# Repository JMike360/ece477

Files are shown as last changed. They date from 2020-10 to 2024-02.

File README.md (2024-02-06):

# ece477
Purdue ECE senior design project of team 8 for Fall 2020  
  
## Team members
John Michael Bolinder (Team leader, software engineer, systems engineer)  
Ethan Rodriguez (Systems engineer, secondary software engineer)  
Jiahui Zhu (Software engineer, secondary hardware engineer)  
Andrew Gan (Hardware engineer, secondary systems engineer)  

## Overview
Skeleton Key is a convenient, fully-featured password management solution, completely client-side with no dependence on a cloud service provider or network connection. The device utilizes an ESP32 microcontroller and onboard peripherals to manage encrypted-at-rest password storage, fingerprint-based authentication for easy and secure access to passwords, and interfaces with a client desktop app to wirelessly retrieve passwords via bluetooth or retrieve passwords through a wired USB connection. Passwords transmitted by USB or Bluetooth are encrypted in-flight, and the desktop application provides easy access to passwords on the target user device.
  
## Tools used
USB URT module  
ESP32  
Fingerprint reader  
SD card  
SD card reader  
LCD module  
  
## GPIO table
| GPIO PIN | Function  | Endpoint |
|---|---|---|
| 1 | U0TXD | FT232 RXD |
| 3 | U0RXD | FT232 TXD |
| 9 | U1RXD | Console in |
| 10 | U1TXD | Console_out  |
| 12 | HSPI_MISO | MicroSD Dout |
| 13 | HSPI_MOSI | MicroSD Din  |
| 14 | HSPI_CLK  | MicroSD CLK  |
| 15 | HSPI_CS0  | MicroSD CS |
| 16 | U2RXD | Fingerprint Scanner TX |
| 17 | U2TXD | Fingerprint Scanner RX |
  
UART 0: console/debug  
UART 1: ESP32 - GUI  
UART 2: ESP32 - Fingerprint  
  
GPIO 6-11 - SPI flash  
GPIO 34-39 - input mode only    
[Full layout](https://microcontrollerslab.com/wp-content/uploads/2019/02/ESP32-pinout-mapping.png)  
ESP32 tech ref manual page 57-58  
  
## References
[ESP32 SPI MASTER API](https://docs.espressif.com/projects/esp-idf/en/latest/esp32/api-reference/peripherals/spi_master.html)

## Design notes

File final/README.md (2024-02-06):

# ESP32 Embedded Software for management of at-rest AES encryption/decryption and in-flight RSA encryption/decryption

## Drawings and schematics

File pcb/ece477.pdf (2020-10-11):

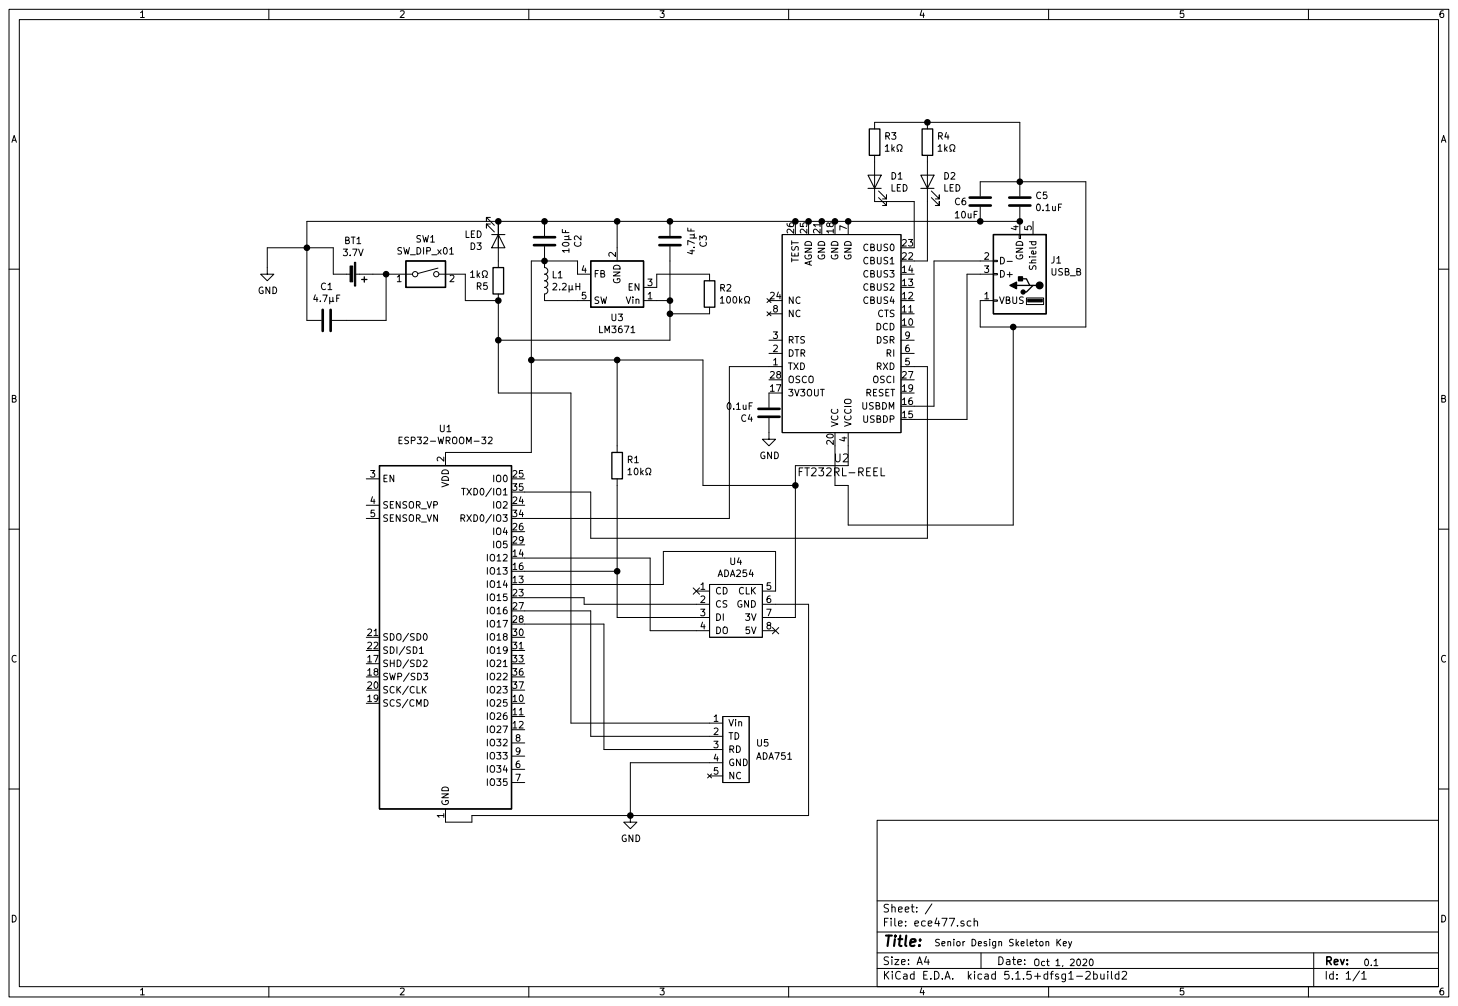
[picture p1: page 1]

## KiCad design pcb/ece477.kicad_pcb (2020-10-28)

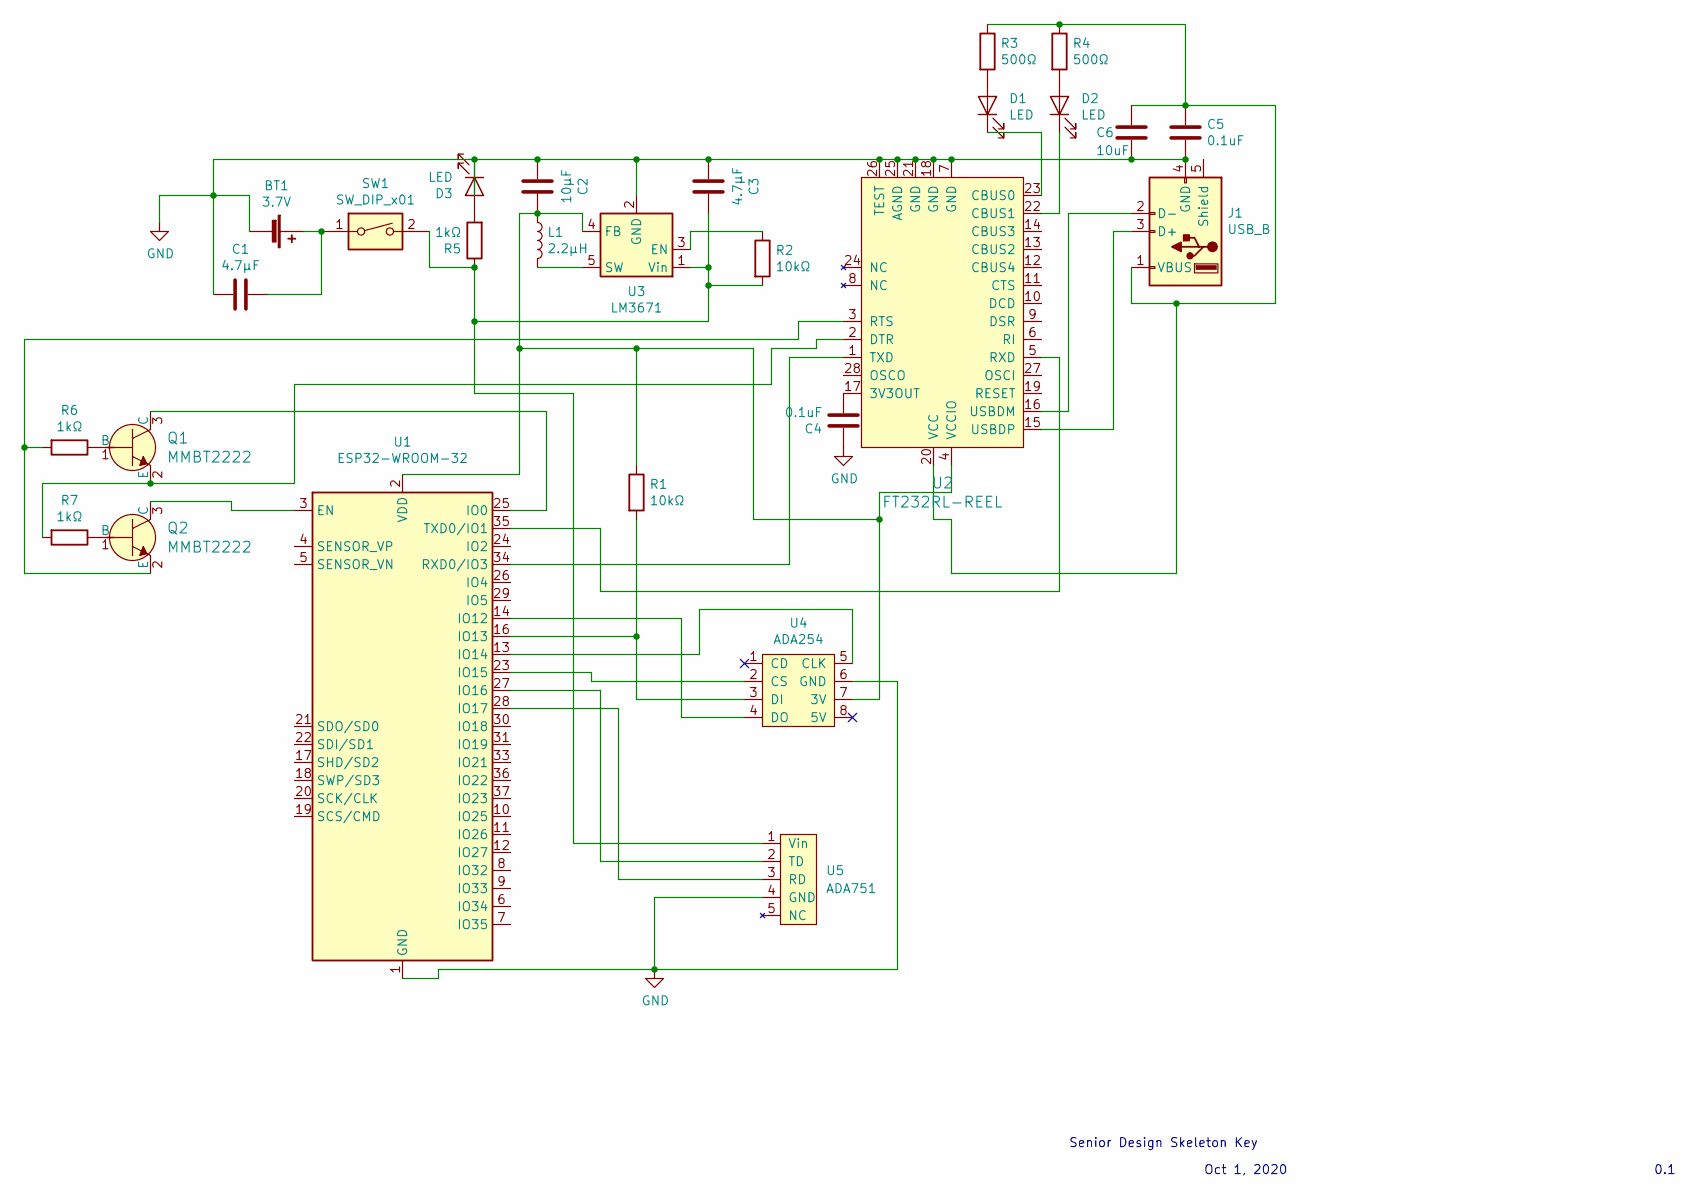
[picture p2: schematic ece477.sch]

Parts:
BT1: 3.7V; PinHeader_1x02_P2.54mm_Vertical
C1, C3: 4.7µF; C_0805_2012Metric
C2: 10µF; C_0805_2012Metric
C4, C5: 0.1uF; C_0805_2012Metric
C6: 10uF; C_0805_2012Metric
D1, D2, D3: LED; LED_0805_2012Metric
J1: USB_B; USB_Micro-B_Molex_47346-0001
L1: 2.2µH; IND_LQH3NPN2R2MMEL
Q1, Q2: MMBT2222; SOT-23-3; MPN MMBT2222A-7-F; Digi-Key_PN MMBT2222A-FDICT-ND
R1, R2: 10kΩ; R_0805_2012Metric
R3, R4: 500Ω; R_0805_2012Metric
R5, R6, R7: 1kΩ; R_0805_2012Metric
SW1: SW_DIP_x01; SW_DIP_SPSTx01_Slide_6.7x4.1mm_W6.73mm_P2.54mm_LowProfile_J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
U1: ESP32-WROOM-32; ESP32-WROOM-32D
U2: FT232RL-REEL; SSOP-28_W5.30mm; MPN FT232RL-REEL; Digi-Key_PN 768-1007-1-ND
U3: LM3671; TSOT-23-5
U4: ADA254; PinSocket_1x08_P2.54mm_Vertical
U5: ADA751; PinHeader_1x05_P2.54mm_Vertical

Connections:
GND: BT1.2 (-), C1.1, C2.1, C3.1, C4.1, C5.2, C6.2, D3.1 (K), J1.4 (GND), U1.1 (GND), U1.15 (GND), U1.38 (GND), U1.39 (GND), U2.7 (GND), U2.18 (GND), U2.21 (GND), U2.25 (AGND), U2.26 (TEST), U3.2 (GND), U4.6 (GND), U5.4 (GND)
unnamed: BT1.1 (+), C1.2, SW1.1
unnamed: C2.2, L1.1, R1.1, U1.2 (VDD), U2.4 (VCCIO), U3.4 (FB), U4.7 (3V)
unnamed: C3.2, R2.2, R5.1, SW1.2, U3.1 (Vin), U5.1 (Vin)
unnamed: C4.2, U2.17 (3V3OUT)
unnamed: C5.1, C6.1, J1.1 (VBUS), R3.1, R4.1, U2.20 (VCC)
unnamed: D1.1 (K), U2.23 (CBUS0)
unnamed: D1.2 (A), R3.2
unnamed: D2.1 (K), U2.22 (CBUS1)
unnamed: D2.2 (A), R4.2
unnamed: D3.2 (A), R5.2
unnamed: J1.2 (D-), U2.16 (USBDM)
unnamed: J1.3 (D+), U2.15 (USBDP)
unnamed: L1.2, U3.5 (SW)
unnamed: Q1.1 (B), R6.1
unnamed: Q1.2 (E), R7.2, U2.2 (DTR)
unnamed: Q1.3 (C), U1.25 (IO0)
unnamed: Q2.1 (B), R7.1
unnamed: Q2.2 (E), R6.2, U2.3 (RTS)
unnamed: Q2.3 (C), U1.3 (EN)
unnamed: R1.2, U1.16 (IO13), U4.3 (DI)
unnamed: R2.1, U3.3 (EN)
unnamed: U1.13 (IO14), U4.5 (CLK)
unnamed: U1.14 (IO12), U4.4 (DO)
unnamed: U1.23 (IO15), U4.2 (CS)
unnamed: U1.27 (IO16), U5.2 (TD)
unnamed: U1.28 (IO17), U5.3 (RD)
unnamed: U1.34 (RXD0/IO3), U2.1 (TXD)
unnamed: U1.35 (TXD0/IO1), U2.5 (RXD)

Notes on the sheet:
Senior Design Skeleton Key
Oct 1, 2020
0.1

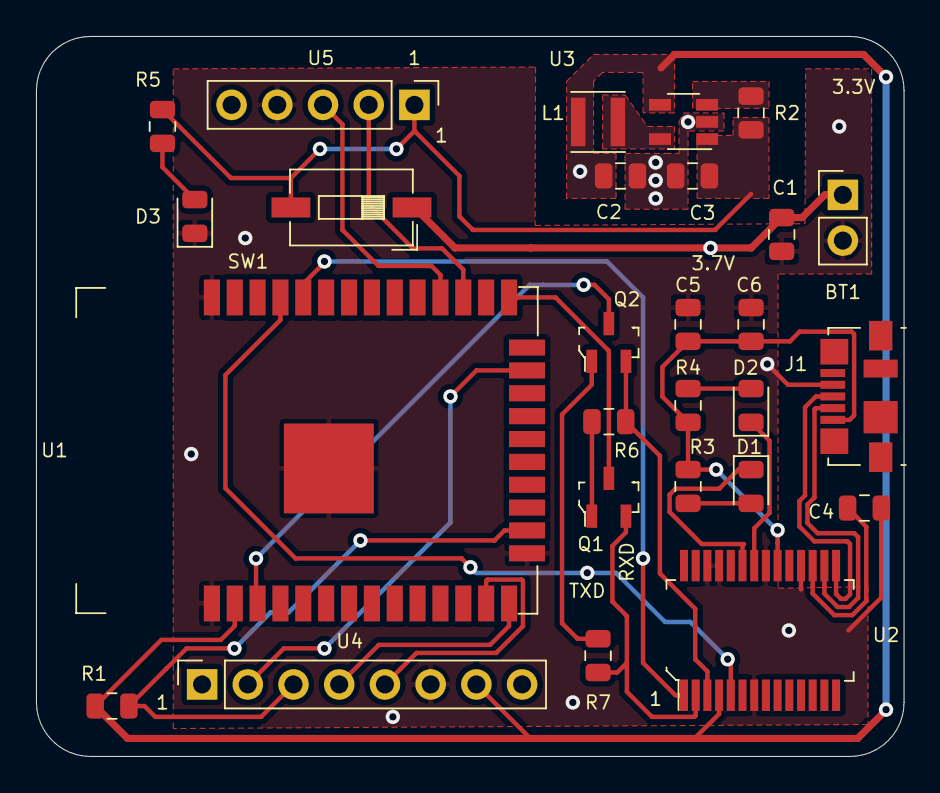
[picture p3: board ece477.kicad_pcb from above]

Board: 2 copper layers, 48.2 x 40.0 mm, 27 parts (0 on the bottom side), 29 nets.

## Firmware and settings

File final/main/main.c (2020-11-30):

#include <stdio.h>
#include <stdbool.h>
#include <string.h>
#include "../include/cmd.h"
#include "freertos/FreeRTOS.h"
#include "freertos/task.h"
#include "sdkconfig.h"
#include "esp_vfs_fat.h"
#include "esp_log.h"
#include <unistd.h>

#include "../include/bt.h"
#include "../include/sdcard.h"
#include "../include/manifest.h"
#include "../include/fingerprint.h"
#include "../include/my_rsa.h"

#define BUF_SIZE_MAIN (1024)
#define TAG "MAIN"

void ledInit(void) {
    gpio_pad_select_gpio(GPIO_GREEN);
    gpio_pad_select_gpio(GPIO_RED);
    gpio_set_direction(GPIO_GREEN, GPIO_MODE_OUTPUT);
    gpio_set_direction(GPIO_RED, GPIO_MODE_OUTPUT);
    ESP_LOGI(TAG, "Successfully initialized LED GPIO");
}

void readUARTCMD(uint8_t* data) {
    int i = 0;
    do {
        i += uart_read_bytes(UART_NUM_0, &data[i], BUF_SIZE_MAIN, 20 / portTICK_RATE_MS);
    } while(data[i-1] != '\n');
    // ESP_LOGI(TAG, "reading from UART: %s\n", data);
    if (data[0] != '#')
        return;
    doCMD(data, UART_MODE);
}

void app_main(void) {
    sdspiInit();
    mountSD();
    ledInit();
    btInit();
    btRegister();
    btSetPairing();
    sleep(2);
    
    uart_begin(UART_NUM_0);
    uart_begin(UART_NUM_2);
    my_rsa_init();

    sleep(2);
    ESP_LOGI(TAG, "All initialization complete");

    while (checkFingerEnrolled() == 0) {
        if (enrollFinger(0) == -1)
            ESP_LOGE(TAG, "Fingerprint enrollment failed");
    }

    if (readManifestToMemory() == MANIFEST_FAILURE)
        return;

    uint8_t* data = (uint8_t*) malloc(BUF_SIZE_MAIN);
    while(getRunning()) {
        memset(data, 0, BUF_SIZE_MAIN);
        readUARTCMD(data);
    }
    free(data);

    if (writeManifestToFile() == MANIFEST_FAILURE)
        return;
    if (deallocateManifest() == MANIFEST_FAILURE)
        return;

    unmountSD();
    uart_end(UART_NUM_0);
    uart_end(UART_NUM_2);
}

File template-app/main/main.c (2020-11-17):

/* Hello World Example

   This example code is in the Public Domain (or CC0 licensed, at your option.)

   Unless required by applicable law or agreed to in writing, this
   software is distributed on an "AS IS" BASIS, WITHOUT WARRANTIES OR
   CONDITIONS OF ANY KIND, either express or implied.
*/
#include <stdio.h>
#include <stdlib.h>
#include "freertos/FreeRTOS.h"
#include "freertos/task.h"
#include "esp_system.h"
#include "esp_spi_flash.h"
#include "crypto_test.h"
#include "fingerprint_test.h"
#include "uart_setup.h"


void app_main(void)
{
    printf("Hello world!\n");

    /* Print chip information */
    esp_chip_info_t chip_info;
    esp_chip_info(&chip_info);
    printf("This is ESP32 chip with %d CPU cores, WiFi%s%s, ",
            chip_info.cores,
            (chip_info.features & CHIP_FEATURE_BT) ? "/BT" : "",
            (chip_info.features & CHIP_FEATURE_BLE) ? "/BLE" : "");

    printf("silicon revision %d, ", chip_info.revision);

    printf("%dMB %s flash\n", spi_flash_get_chip_size() / (1024 * 1024),
            (chip_info.features & CHIP_FEATURE_EMB_FLASH) ? "embedded" : "external");

    for (int i = 10; i >= 0; i--) {
        printf("Restarting in %d seconds...\n", i);
        vTaskDelay(1000 / portTICK_PERIOD_MS);
    }

    encodetest();

    printf("Running test shell\n");
    int cmd = -1;
    const char* const cmdList[] = {
        "0. Exit\n",
        "1. Send Handshake\n",
        "2. Library Handshake\n",
        "3. Library Generate Img\n",
        "4. Library Capture Image\n",
        "5. Library Generate File From Image (Buffer 1)\n",
        "6. Library Generate File From Image (Buffer 2)\n",
        "7. Library Generate Template\n",
        "8. Library Store Template\n",
        "9. Library Match Search\n",
        "10. Library Load Template\n",
        "11. Library Clear All Templates\n",
        "12. Download Fingerprint Image\n",
        "13. Read System Parameters\n",
        "14. Create Crypto Key\n",
        "15. Led Control\n",
        "16. High Level Check Finger Enrolled\n",
        "17. High Level Enroll Finger\n",
        "18. High Level Authenticate Finger\n",
        "19. High Level Get Crypto Key\n",
        "20. High Level Clear All Data\n"
    };
    setupFtdiConsole();
    while (cmd != 0){
        printf("\n\nAvailable commands:\n");
        for(int i = 0; i < 21; i++){
            printf("%s", cmdList[i]);
        }
        printf("Please enter desired sensor command as number...\n");
        cmd = getFtdiCommand();
        printf("\n\n"); 
        switch(cmd){
            case 0:
                printf("Exiting test shell...\n");
                break;
            case 1:
                printf("Running raw handshake command...\n");
                sendHandshake();
                break;
            case 2:
                printf("Running library handshake test...\n");
                testLibraryHandshake();
                break;
            case 3:
                printf("Running library generate image test...\n");
                testLibraryGenImg();
                break;
            case 4:
                printf("Running library capture image test...\n");
                testLibraryCaptureImage();
                break;
            case 5:
                printf("Running library generate file from image (buffer 1) test...\n");
                testLibraryGenerateFileFromImg(0x01);
                break;
            case 6:
                printf("Running library generate file from image (buffer 2) test...\n");
                testLibraryGenerateFileFromImg(0x02);
                break;
            case 7:
                printf("Running library generate template test...\n");
                testLibraryGenerateTemplate();
                break;
            case 8:
                printf("Running library store template test...\n");
                printf("Please enter an ID for storing template...\n");
                uint16_t pageID_store = (uint16_t)getFtdiCommand();
                printf("Storing template under ID: %d...", pageID_store);
                testLibraryStoreTemplate(pageID_store);
                break;
            case 9:
                printf("Running match search test...\n");
                testLibraryMatchSearch(0x01);
                break;
            case 10:
                printf("Running load template test...\n");
                printf("Please enter the template ID to load...\n");
                uint16_t pageID_load = (uint16_t)getFtdiCommand();
                printf("Please enter desired buffer to load to...\n");
                uint8_t bufferID = (uint8_t)getFtdiCommand();
                printf("Attempting to load template %d to buffer %d...\n", pageID_load, bufferID);
                testLibraryLoadTemplate(bufferID, pageID_load);
                break;
            case 11:
                printf("Running clear template library test...\n");
                testLibraryClearTemplates();
                break;
            case 12:
                printf("Running download template file test...\n");
                testLibraryUploadFile(0x01);
                break;
            case 13:
                printf("Running system parameter read test...\n");
                testLibraryReadParam();
                break;
            case 14:
                printf("Running crypto key generation test...\n");
                testLibraryGenerateCryptoKey();
                break;
            case 15:
                printf("Running led control test...\n");
                printf("Please select 1 for led on or 0 for led off...\n");
                int state = getFtdiCommand();
                testLibraryLedCtrl(state);
                break;
            case 16:
                printf("Running high level check finger enrolled...\n");
                testHLcheckFingerEnrolled();
                break;
            case 17:
                printf("Running high level enroll finger...\n");
                testHLenrollFinger();
                break;
            case 18:
                printf("Running high level authenticate finger...\n");
                testHLauthenticateFinger();
                break;
            case 19:
                printf("Running high level get crypto key...\n");
                testHLgetCryptoKey();
                break;
            case 20:
                printf("Running high level clear all data...\n");
                testHLclearAllData();
                break;
            default:
                printf("Unknown command, please select a command from the list\n");
                break;
        }
    }
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

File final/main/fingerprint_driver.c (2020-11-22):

#include "esp_log.h"
#include "../include/fingerprint_driver.h"

#define TAG "FINGERPRINT"

sensor_packet* createPacket(uint8_t pid, uint16_t length, uint8_t* data, uint16_t checksum){
    sensor_packet* pkt = malloc(sizeof(sensor_packet));
    pkt->header = PKT_HEADER;
    pkt->addr[0] = 0xFF;
    pkt->addr[1] = 0xFF;
    pkt->addr[2] = 0xFF;
    pkt->addr[3] = 0xFF;
    pkt->pid = pid;
    pkt->length = length;
    pkt->data = malloc(sizeof(uint8_t)*(length-2));
    for(int i = 0; i < length-2; i++){
        pkt->data[i] = data[i];
    }
    pkt->checksum = checksum;
    return pkt;
}

void freePacket(sensor_packet* pkt){
    free(pkt->data);
    free(pkt);
}

bool isEqual(sensor_packet* pkt1, sensor_packet* pkt2){
    bool isEqual = true;
    isEqual &= (pkt1->header == pkt2->header);
    isEqual &= (pkt1->addr[0] == pkt2->addr[0]);
    isEqual &= (pkt1->addr[1] == pkt2->addr[1]);
    isEqual &= (pkt1->addr[2] == pkt2->addr[2]);
    isEqual &= (pkt1->addr[3] == pkt2->addr[3]);
    isEqual &= (pkt1->pid == pkt2->pid);
    isEqual &= (pkt1->length == pkt2->length);
    for(int i = 0; i < pkt1->length-2; i++){
        if((i >= pkt2->length-2) || (!isEqual)){
            break;
        }
        isEqual &= (pkt1->data[i] == pkt2->data[i]);
    }
    isEqual &= (pkt1->checksum == pkt2->checksum);
    return isEqual;
}

void printPacket(sensor_packet* pkt){
    #ifdef _DEBUG
    ESP_LOGI(TAG, "Header: 0x%04x", pkt->header);
    ESP_LOGI(TAG, "Addr: 0x%02x 0x%02x 0x%02x 0x%02x", pkt->addr[0], pkt->addr[1], pkt->addr[2], pkt->addr[3]);
    ESP_LOGI(TAG, "PID: 0x%02x", pkt->pid);
    ESP_LOGI(TAG, "Length: 0x%04x", pkt->length);
    ESP_LOGI(TAG, "Data:");
    for(int i = 0; i < pkt->length-2; i++){
        if((i%8)==0){
            ESP_LOGI(TAG, "");
        }
        else{
            ESP_LOGI(TAG, " ");
        }
        ESP_LOGI(TAG, "0x%02x", pkt->data[i]);
    }
    ESP_LOGI(TAG, "");
    ESP_LOGI(TAG, "Checksum: 0x%04x", pkt->checksum);
    #endif
}

void processResponse(uint8_t response){
    #ifdef _DEBUG
    switch(response){
        case ACK_CMD_COMPLETE:
            ESP_LOGI(TAG, "Command completed successfully");
            break;
        case ACK_RCV_ERR:
            ESP_LOGI(TAG, "Error receiving packet");
            break;
        case ACK_NO_FINGER:
            ESP_LOGI(TAG, "No finger detected on sensor");
            break;
        case ACK_ENROLL_FAIL:
            ESP_LOGI(TAG, "Failed to enroll fingerprint");
            break;
        case ACK_IMG_UNCLEAR:
            ESP_LOGI(TAG, "Failed to generate char file - Image unclear");
            break;
        case ACK_IMG_SMALL:
            ESP_LOGI(TAG, "Failed to generate char file - Image too small");
            break;
        case ACK_NO_MATCH:
            ESP_LOGI(TAG, "Finger does not match");
            break;
        case ACK_MATCH_NOT_FOUND:
            ESP_LOGI(TAG, "Failed to find matching finger in library");
            break;
        case ACK_CHAR_MERGE_ERR:
            ESP_LOGI(TAG, "Failed to merge char files");
            break;
        case ACK_BAD_ADDR:
            ESP_LOGI(TAG, "PageID address is out of range for finger library");
            break;
        case ACK_TEMPLATE_ERR:
            ESP_LOGI(TAG, "Error reading template from library, or invalid template");
            break;
        case ACK_TEMP_UPLOAD_ERR:
            ESP_LOGI(TAG, "Error uploading template");
            break;
        case ACK_NO_DATA_ACCEPT:
            ESP_LOGI(TAG, "Sensor is not ready for additional data packets");
            break;
        case ACK_IMG_UPLOAD_ERR:
            ESP_LOGI(TAG, "Error uploading image");
            break;
        case ACK_DEL_TEMP_FAIL:
            ESP_LOGI(TAG, "Failed to delete requested template");
            break;
        case ACK_CLEAR_LIB_FAIL:
            ESP_LOGI(TAG, "Failed to clear fingerprint library");
            break;
        case ACK_BAD_PASSWORD:
            ESP_LOGI(TAG, "Operation failed due to incorrect password");
            break;
        case ACK_BAD_PRIMARY_IMG:
            ESP_LOGI(TAG, "Failed to generate image - primary image invalid");
            break;
        case ACK_FLASH_WRITE_ERR:
            ESP_LOGI(TAG, "Error when writing to flash");
            break;
        case ACK_NO_DEF_ERR:
            ESP_LOGI(TAG, "Undefined error");
            break;
        case ACK_INVALID_REG:
            ESP_LOGI(TAG, "Invalid register number");
            break;
        case ACK_BAD_REG_CONFIG:
            ESP_LOGI(TAG, "Incorrect register configuration");
            break;
        case ACK_BAD_NOTEPAD_PG:
            ESP_LOGI(TAG, "Invalid notepad page number");
            break;
        case ACK_COMM_PORT_FAIL:
            ESP_LOGI(TAG, "Failed to operate the communication port");
            break;
        case ACK_ADDR_ERR:
            ESP_LOGI(TAG, "Address error");
            break;
        case ACK_PWD_NO_VERIFIED:
            ESP_LOGI(TAG, "Error - passowrd not verified");
            break;
        default:
            ESP_LOGI(TAG, "Error - unknown response code");
            break;
    }
    #endif
}

int sendPacketAsByteStream(sensor_packet* pkt){
    if(pkt == NULL){
        return -1;
    }

    size_t streamSize = sizeof(pkt->header) +
                        sizeof(pkt->pid) +
                        sizeof(pkt->addr[0])*4 +
                        sizeof(pkt->length) +
                        sizeof(uint8_t)*(pkt->length);
    #ifdef _DEBUG
    ESP_LOGI(TAG, "Stream size: %d", (int)streamSize);
    #endif
    char* byteStream = malloc(streamSize);
    byteStream[0] = (const char)(pkt->header >> 8);
    byteStream[1] = (const char)(pkt->header & 0xFF);
    byteStream[2] = (const char) pkt->addr[0];
    byteStream[3] = (const char) pkt->addr[1];
    byteStream[4] = (const char) pkt->addr[2];
    byteStream[5] = (const char) pkt->addr[3];
    byteStream[6] = (const char) pkt->pid;
    byteStream[7] = (const char)(pkt->length >> 8);
    byteStream[8] = (const char)(pkt->length & 0xFF);
    int offset = 9;
    int i = offset;
    for(; i < offset+pkt->length-2; i++){
        byteStream[i] = pkt->data[i-offset];
    }
    byteStream[i] = (const char)(pkt->checksum >> 8);
    byteStream[i+1] = (const char)(pkt->checksum & 0xFF);
    /*ESP_LOGI(TAG, "Bytes sent:");
    for(int j = 0; j < i+2; j++){
        ESP_LOGI(TAG, "0x%02x", byteStream[j]);
    }*/
    int result = uart_write_bytes(UART_NUM_2, byteStream, streamSize);
    #ifdef _DEBUG
    if(result == -1){
        ESP_LOGI(TAG, "Parameter error when sending uart packet");
    }
    #endif
    free(byteStream);
    return result;
}
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

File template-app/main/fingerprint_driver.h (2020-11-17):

#include "esp_system.h"
#include "uart_setup.h"
#include "crypto_test.h"

#define PORT_NUM PORT_NUM_2
#define DATA_PKT_SIZE 128

#define PKT_HEADER   0xEF01
#define PKT_ADDR    0xFFFFFFFF
#define PKT_PID_CMD  0x01
#define PKT_PID_DAT  0x02
#define PKT_PID_ACK  0x07
#define PKT_PID_END  0x08
#define PKT_LENGTH   0 // Length of packet content (CMD and DATA packets) plus length of checksum (2bytes) Measured in bytes
                     // Max length of 256 bytes. High byte transferred first
#define PKT_DATA     0   //Commands, data, command params, ack result, etc.
#define PKT_CHECKSUM 0 //2 bytes, arithmetic sum of PID, packet length, and all packet contents. Overflowing bits omitted, high byte transferred first

#define ACK_CMD_COMPLETE    0x00
#define ACK_RCV_ERR         0x01
#define ACK_NO_FINGER       0x02
#define ACK_ENROLL_FAIL     0x03
#define ACK_IMG_UNCLEAR     0x06
#define ACK_IMG_SMALL       0x07
#define ACK_NO_MATCH        0x08
#define ACK_MATCH_NOT_FOUND 0x09
#define ACK_CHAR_MERGE_ERR  0x0A
#define ACK_BAD_ADDR        0x0B
#define ACK_TEMPLATE_ERR    0x0C
#define ACK_TEMP_UPLOAD_ERR 0x0D
#define ACK_NO_DATA_ACCEPT  0x0E
#define ACK_IMG_UPLOAD_ERR  0x0F
#define ACK_DEL_TEMP_FAIL   0x10
#define ACK_CLEAR_LIB_FAIL  0x11
#define ACK_BAD_PASSWORD    0x13
#define ACK_BAD_PRIMARY_IMG 0x15
#define ACK_FLASH_WRITE_ERR 0x18
#define ACK_NO_DEF_ERR      0x19
#define ACK_INVALID_REG     0x1A
#define ACK_BAD_REG_CONFIG  0x1B
#define ACK_BAD_NOTEPAD_PG  0x1C
#define ACK_COMM_PORT_FAIL  0x1D
#define ACK_ADDR_ERR        0x20
#define ACK_PWD_NO_VERIFIED 0x21
//RX/TX pins on the feather board are labelled as 16RX - GPIO3 / 17TX - GPIO1 for the UART0 port

#define _DEBUG

typedef struct sensor_packet {
    uint16_t header;
    uint8_t addr[4];
    uint8_t  pid;
    uint16_t length;
    uint8_t* data;
    uint16_t checksum;
} sensor_packet;

sensor_packet* createPacket(uint8_t pid, uint16_t length, uint8_t* data, uint16_t checksum);
void freePacket(sensor_packet* pkt);

//-------------------------------------------------//
//------------ High Level Sensor Functions --------//
//-------------------------------------------------//

int captureImage(int timeout_ms);
int checkFingerEnrolled(); //returns 1 if enrolled fingerprint template is found, 0 otherwise
int enrollFinger(int templateID); //returns 0 on success, -1 otherwise
int authenticateFinger(); //returns 1 if finger matches, 0 otherwise
int getCryptoKey(uint8_t** key, int* keySize); //Params: uint8_t** key is the pointer to a uint8_t* to which digest data will be assigned (can be NULL, must be free()'d later)
                                               //        int* keySize is a pointer whose referenced value will be assigned the digest size
                                               //returns 0 for success, -1 otherwise
int clearAllData(); //returns 0 on success, -1 otherwise

//-------------------------------------------------//
//------------ Low Level Packet Functions ---------//
//-------------------------------------------------//

int sendHandshakePacket();
int recvHandshakeAck();

int sendSetSystemParamPacket(uint8_t paramNumber, uint8_t content);
int recvSetSystemParamAck();

int sendReadSystemParamPacket();
int recvReadSystemParamAck();

int sendReadTemplateNumPacket();
int recvReadTemplateNumAck();

int sendGenerateImgPacket();
int recvGenerateImgAck();

int sendUploadImgPacket();
int recvUploadImgAck();

int sendDownloadImgPacket();
int recvDownloadImgAck();

int sendGenerateFileFromImgPacket(uint8_t bufferID);
int recvGenerateFileFromImgAck();

int sendGenerateTemplatePacket();
int recvGenerateTemplateAck();

int sendUploadFilePacket(uint8_t bufferID);
int recvUploadFileAck(uint8_t** charFile, int* size);

int sendDownloadFilePacket();
int recvDownloadFileAck();

int sendStoreTemplatePacket(uint8_t bufferID, uint16_t pageID);
int recvStoreTemplateAck();

int sendLoadTemplatePacket(uint8_t bufferID, uint16_t pageID);
int recvLoadTemplateAck();

int sendDeleteTemplatePacket();
int recvDeleteTemplateAck();

int sendClearLibraryPacket();
int recvClearLibraryAck();

int sendCheckMatchPacket();
int recvCheckMatchAck();

int sendSearchLibraryPacket(uint8_t bufferID, uint16_t startPage, uint16_t n);
int recvSearchLibraryAck();

int sendGenerateRandomNumPacket();
int recvGenerateRandomNumAck();

int sendWriteNotepadPacket();
int recvWriteNotepadAck();

int sendReadNotepadPacket();
int recvReadNotepadAck();

int sendTurnLedOnPacket();
int recvTurnLedOnAck();

int sendTurnLedOffPacket();
int recvTurnLedOffAck();

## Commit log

2020-09-03 added FatFS files
    [mkfs.xlsx]
2020-09-03 removed docs
    [mkfs.xlsx]
2020-09-06 added pcb
    [ece477.kicad_pcb, ece477.sch]
2020-09-07 debug SPI
2020-09-09 used a new way to convert data to SPI ready
2020-09-09 include function to convert uint to SPI format
2020-09-15 Update README.md
    Added gpio/pin request
2020-09-15 added fingerprint scanner pins
2020-09-16 template app with crypto tests and uart tests for fingerprint sensor
2020-09-17 Add files via upload
    Demo Template so far for software application.
    Still need to discuss library and functionality
    Help button will link to user manual,
    Project website will link to the ECE 477 team page.
    Connect Device will help users figure out if their device is connected and if they can access the device from the application.
    User Settings will allow a user to put information, put a their fingerprint (cute gif animation and status bar to be added), and have an emergency pin that will reset the device (maybe)
    Password manager will allow user to open a form that will autofill passwords with a click (not decided yet) from saved passwords, or to save new ones. It will also allow you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
2020-09-17 Add files via upload
    CORRECT UPLOAD FOLDER
    Password manager will allow user to open a form that will autofill passwords with a click (not decided yet) from saved passwords, or to save new ones.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
2020-09-18 connected fingerprint scanner in schematic
2020-09-19 added sd card, battery and esp32 qfn to pcb
    [ece477.sch]
2020-09-19 updated pcb
    [ece477.kicad_pcb, ece477.sch]
2020-09-19 added wires to pcb
    [ece477.kicad_pcb, ece477.sch]
2020-10-06 Added fingerprint files
2020-10-07 uploaded pcb files
    [ece477.kicad_pcb, ece477.sch]
2020-10-08 slight pcb changes
    [ece477.kicad_pcb]
2020-10-08 squeezed lm3671 components together
    [ece477.kicad_pcb]
2020-10-08 pcb update
    [ece477.kicad_pcb, ece477.sch]
2020-10-08 shifted LM3671 to top right
    [ece477.kicad_pcb, ece477.sch]
2020-10-09 some fixes not done yet
    [ece477.kicad_pcb, ece477.sch]
2020-10-09 updated C and R size, fixed LM3671
    [ece477.kicad_pcb]
2020-10-10 connected to ground plate
    [ece477.kicad_pcb]
2020-10-11 added power LED
    [ece477.kicad_pcb, ece477.sch]
2020-10-12 fixed LM3671 ground vias
    [ece477.kicad_pcb]
2020-10-14 updated pcb pinheader width
    [ece477.kicad_pcb, ece477.sch]
2020-10-15 gui-blink added
    [ece477.kicad_pcb, ece477.sch]
2020-10-16 script to make led work
2020-10-17 updated pcb with programming transistors
    [ece477.kicad_pcb, ece477.sch]
2020-10-21 pcb final touch
    [ece477.kicad_pcb]
2020-10-22 added uart cmd
    [ece477.kicad_pcb]
2020-10-28 added function description
    [ece477.kicad_pcb]
2020-10-29 Add files via upload
    So far trouble shooting request creds and entries.
    Can do LEDS and Make creds.
    After finishing the request creds/entries, then it be delete for the sd protocols.
    Please for testing go to connections, and go to USB
2020-10-29 updated console output uart num
2020-10-29 updated GPIO pin usage on readme
2020-11-04 merging uart with bluetooth
2020-11-12 Updated fingerprint sensor driver library
2020-11-17 fp sensor driver updates - file download and key generation now complete, additional fixes to sendPacketAsByteStream size calculation
    [fingerprint_driver.c, fingerprint_driver.h, fingerprint_test.c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]
2020-11-17 Added additional led ctrl functions
2020-11-17 added interface for high level fp sensor functions
2020-11-17 added more led turn off commands
2020-11-20 Add files via upload
    Fingerprint scanner, and fixed layout
2020-11-21 fingerprint authentication complete
2020-11-22 user given 3 tries for matching fingerprint
2020-11-24 clear SD data upon fingerprint enrollment
2020-11-24 fixed some decrypt bugs
    [cmd.c, main.c]
2020-11-26 implemented ESP32-side RSA keygen and exchange, encryption and decryption
2020-12-01 Added connection mode processing from the sd card interface form to the fingerprint management form
2020-12-01 wait for connection before fingerprint authentication
2020-12-01 reverting to prev commit
    [cmd.c, main.c]
2020-12-02 attempting to fix RSA formatting issues
    [cmd.c]
